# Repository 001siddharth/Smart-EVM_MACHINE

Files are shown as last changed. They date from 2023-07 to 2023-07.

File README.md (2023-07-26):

# Smart-EVM_MACHINE
**Approach Used** 
- We have stored the votes of each candidate in SR Latches and after the completion of 15 
sec from the first press of voters, the votes will be stored in the counter accumulating all the 
votes from different voters. At the end, you may press a push button to display the winner on 
7-Segment Display <br>
        **Features Added** <br>
  - Votes Comparator: The button named “Display Winner” when pressed compares the votes of all  
four candidates and prints ‘0’ if A wins, ‘1’ if B wins, ‘2’ if C wins, and ‘3’ if D wins. The 
comparator uses 3 four-bit comparator and 2 multiplexers
  - Display of Winner: The winner as output from comparator is shown on a 7-Segment Display for better 
readability on PCB. The Display will only function when the Display Winner button is 
pressed
  - MULTIPLE CANDIDATE VOTING: A voter may cast his vote(s) to any of the four candidates (one or more than one 
candidate) while only once for one candidate. The voter has a total time of 15 seconds in 
which he may cast his votes after which his votes will be registered
  - “Voted For” LEDs: Added four LEDs that display for which candidate the voter has voted. This feature 
removes any uncertainty in the minds of the voter that they might cast a wrong vote. A visual 
confirmation is the best way to remove any such confusion


  - REVERSE THE CASTED VOTE: As the votes are not registered into counters until 15 seconds have passed. The voter has this 15 seconds to alter his voting decisions. We have added four additional buttons to reverse a vote that voter may have casted mistakenly
    
  -  The ‘READY’ LED: As the votes are not registered into counters until 15 seconds have passed. The voter has this 15 seconds to alter his voting 
decisions. We have added four additional buttons to reverse a vote that voter may have cast mistakenly
  - 3 SECOND DELAY : 3-second delay is added after any button to cast a vote is pressed by the voter. 
This feature is to avoid any debouncing caused by the switch. However, as we are using SR 
Latch, which once set will not change its value until reset, overcomes this issue of 
debouncing without introducing any delay in the circuit.<br><br>
                                **PCB-layout**
<br><br>
Here as you can see in this PCB layout design we have generated the clock pulse of 
frequency 1Hz using N555 and with some resistors and capacitors. Each logic gate and 
IC’s VCC and GND terminal is connected with a connector with two inputs. Through pin
no.1 of the connector, we will supply VCC of 5V and Ground through pin no 2. Also, there 
is enable pin which will be activated by supplying 5V. And after enabling it will start 
comparing the votes of the candidates. And the result will be shown In the display attached.
We have done copper filling of Ground only because Filling a via with copper increases its 
thermal conductivity and higher conductivity will lead to high heat and may overheat the 
whole board and also may damage IC’s

<br> 
The Schematic of the Circuit <br>



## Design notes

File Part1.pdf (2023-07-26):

## DIGISIM

### PROBLEM STATEMENT 1 (PART 1)

# Team: Cool Bits

Jasnoor Sandhu (jasnoor.sandhu.ece21@itbhu.ac.in)

Siddharth Atrey (siddharth.atrey.ece21@itbhu.ac.in)

## APPROACH

We have stored the votes of each candidate in SR Latches and after the completion of 15 sec from the first press of voter, the votes will be stored in counter accumulating all the votes from different voters. At end, you may press a push button displaying the winner on 7-Segment Display.

## PCB LAYOUT

Here as you can see in this PCB layout design we have generate the clock pulse of frequency 1Hz using N555 and with some resistors and capacitors. Each logic gates and IC’s VCC and GND terminal is connected with connector with two inputs. Through pin no.1 of the connector we will supply VCC of 5V and Ground through pin no 2 . Also there is enable pin which will be activated by supplying 5V. And after enabling it will start comparing the votes of the candidates. And result will be shown In the display attached.

We have done copper filling of Ground only because Filling a via with copper increases its thermal conductivity and higher conductivity will lead to high heat and may overheat the whole board and also may damage IC’s.

DIGISIM - COOL BITS | 1

## FEATURES

1. VOTES COMPARATOR :
The button named “Display Winner” when pressed compares the votes of all the four candidates and prints ‘0’ if A wins, ‘1’ if B wins, ‘2’ if C wins and ‘3’ if D wins. The comparator uses 3 four-bit comparator and 2 multiplexers.
2. DISPLAY OF WINNER :
The winner as output from comparator is shown on a 7-Segment Display for better readability on PCB. The Display will only function when the Display winner button is pressed.

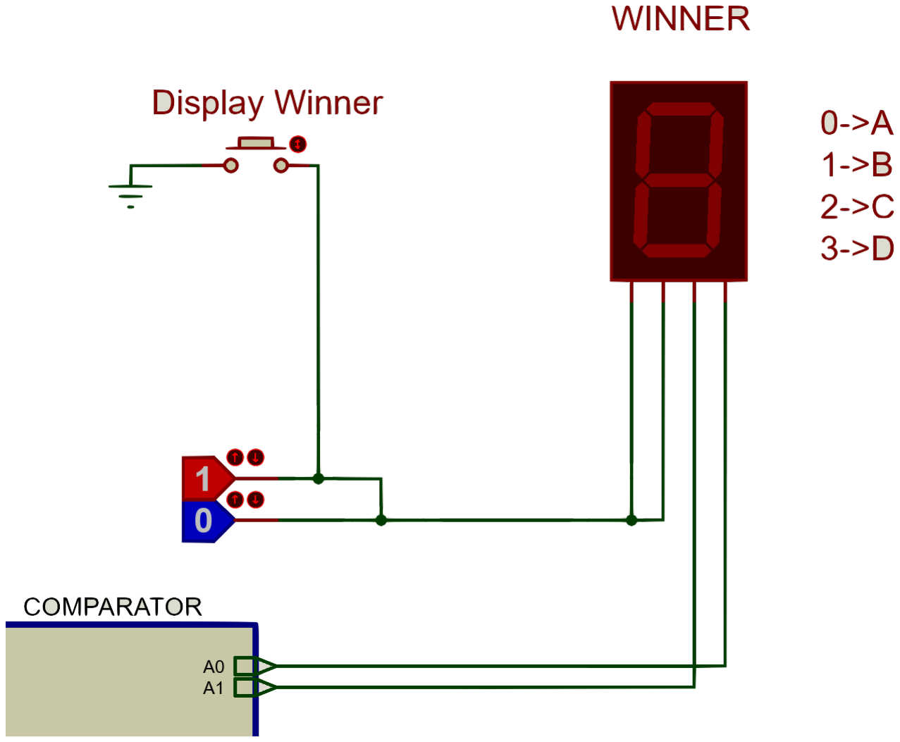
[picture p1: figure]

3. MULTIPLE CANDIDATE VOTING :
A voter may cast his vote(s) to any of the four candidates (one or more than one candidate) while only once for one candidate. The voter has a total time of 15 seconds in which he may cast his votes after which his votes will be registered.
4. “Voted For” LEDs :
Added four LEDs that display for which candidate the voter has voted. This feature removes any uncertainty in minds of the voter that they might cast a wrong vote. A visual confirmation is best way to remove any such confusion

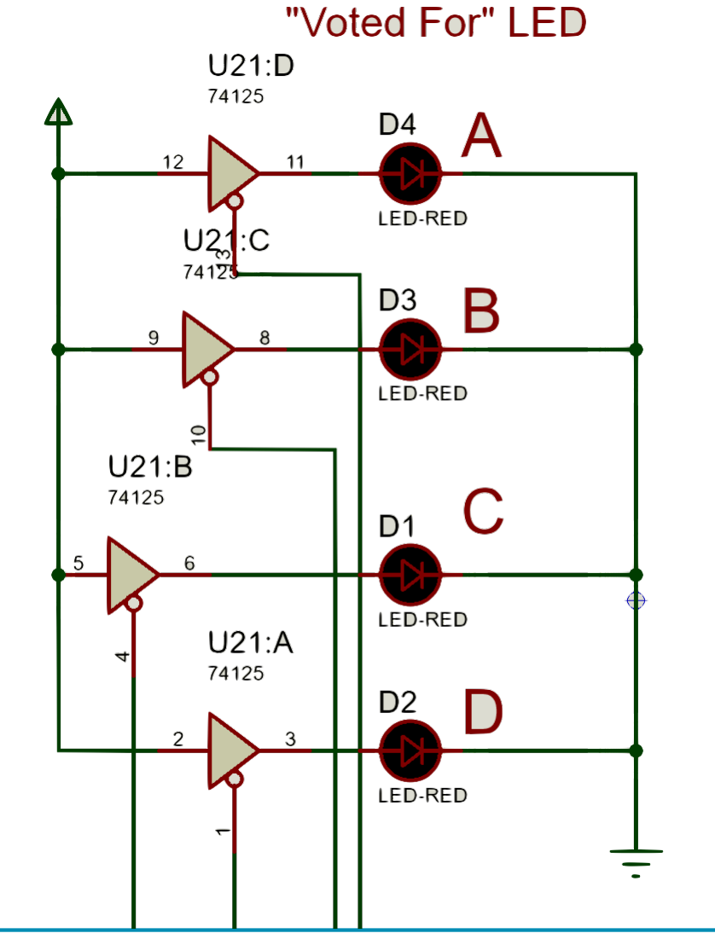
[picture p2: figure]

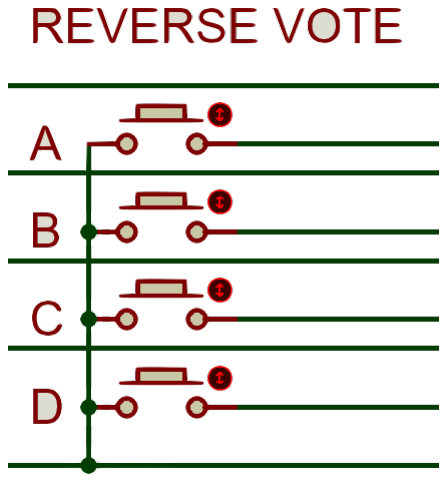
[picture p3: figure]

5. REVERSE THE CASTED VOTE :
As the votes are not registered into counters until 15 seconds have passed. The voter has this 15 seconds to alter his voting decisions. We have added four additional buttons to reverse a vote that voter may have casted mistakenly.
6. THE ‘READY’ LED :

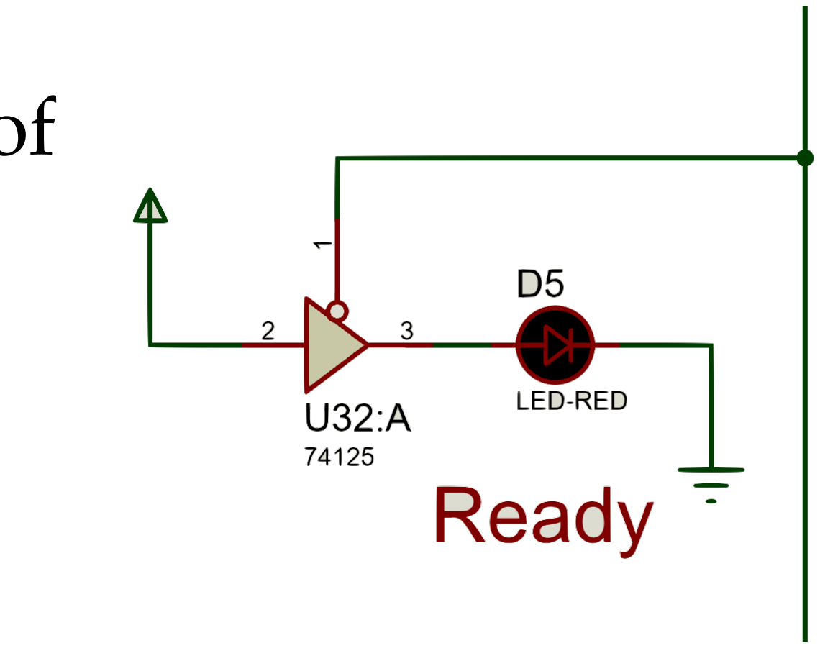
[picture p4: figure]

As the machine doesn’t take input from voter within 3 sec of a button press. A ‘Ready’ LED is present which indicates that the machine is ready for another input. So the user my input another
vote if he wants to.
7. 3 SECOND DELAY :
A 3 second delay is added after any button to cast vote is pressed by the voter. This feature is to avoid any debouncing caused by switch. However, as we are using SR Latch, which once set will not change its value until reset, overcomes this issue of debouncing without introducing any delay in circuit.

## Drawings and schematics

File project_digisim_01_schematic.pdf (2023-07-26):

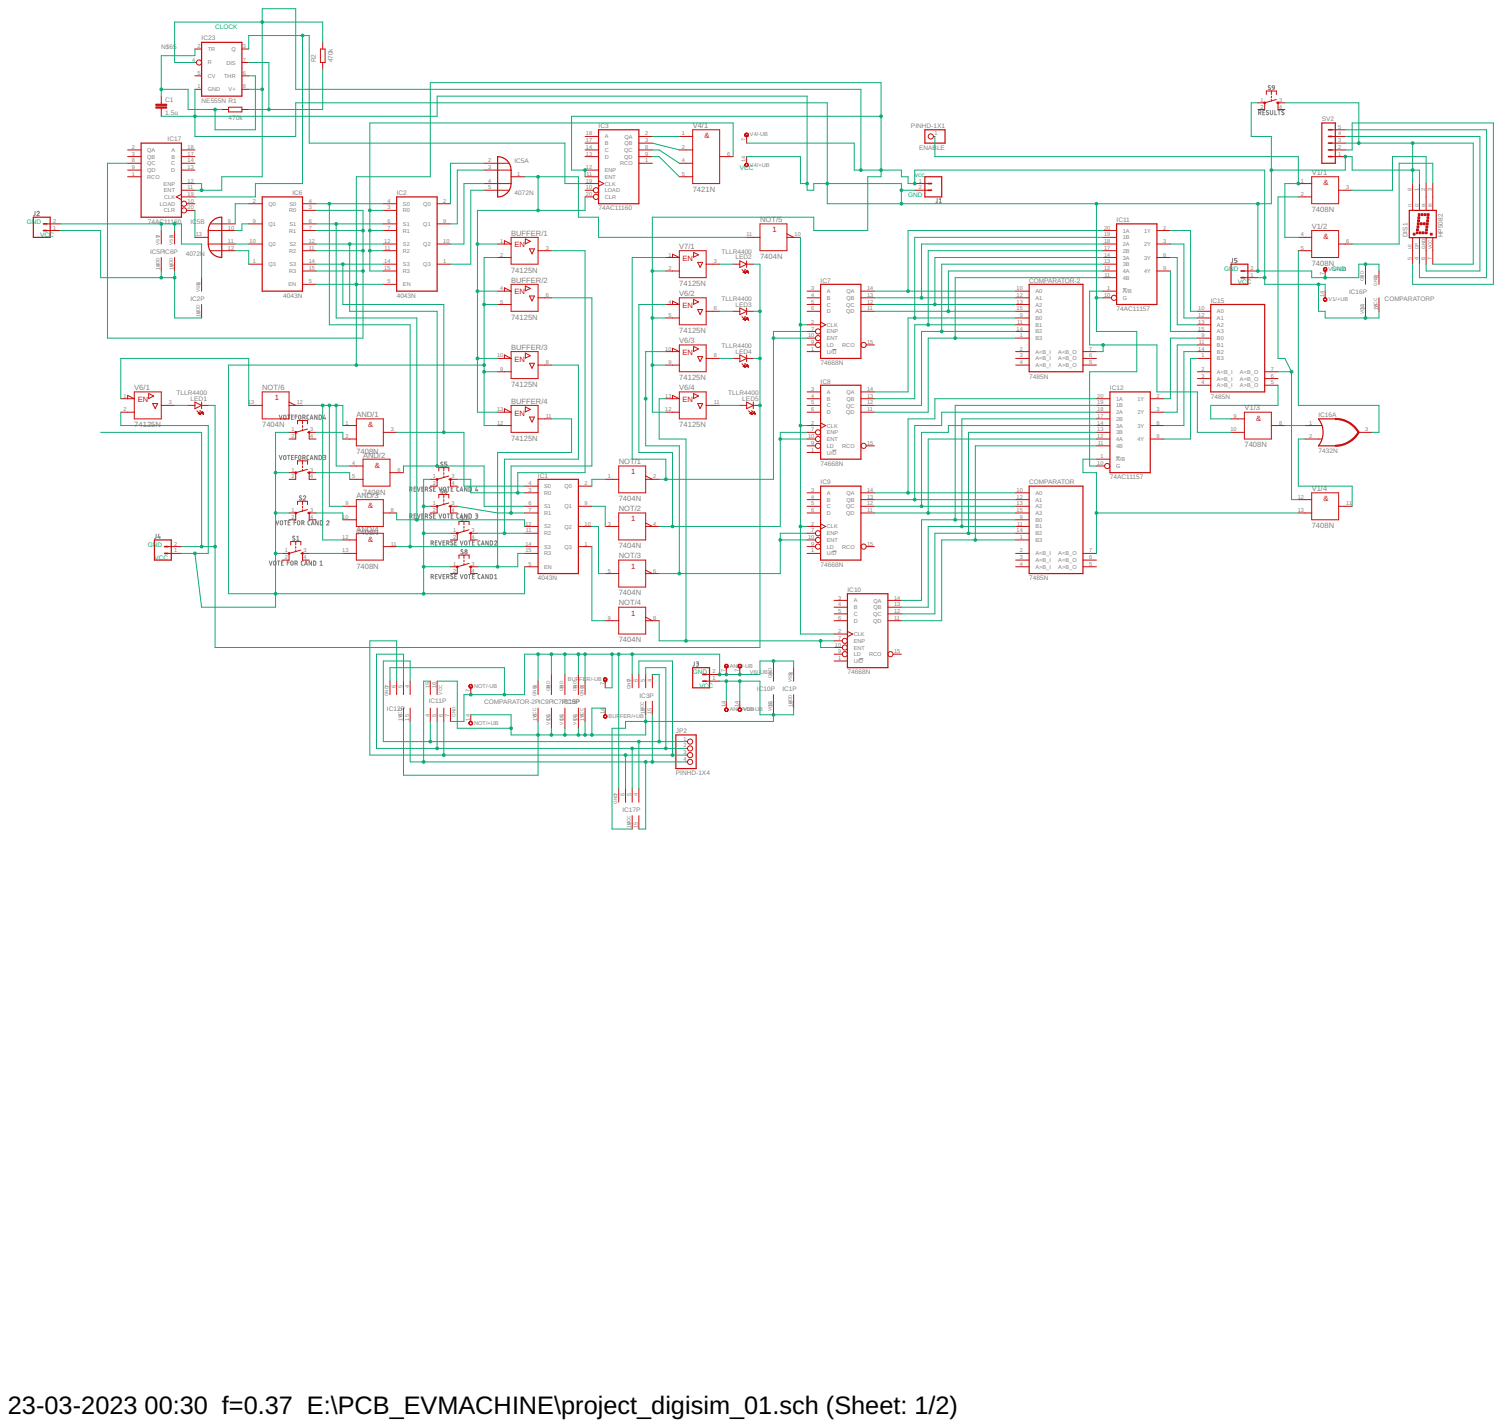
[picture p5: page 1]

3 4

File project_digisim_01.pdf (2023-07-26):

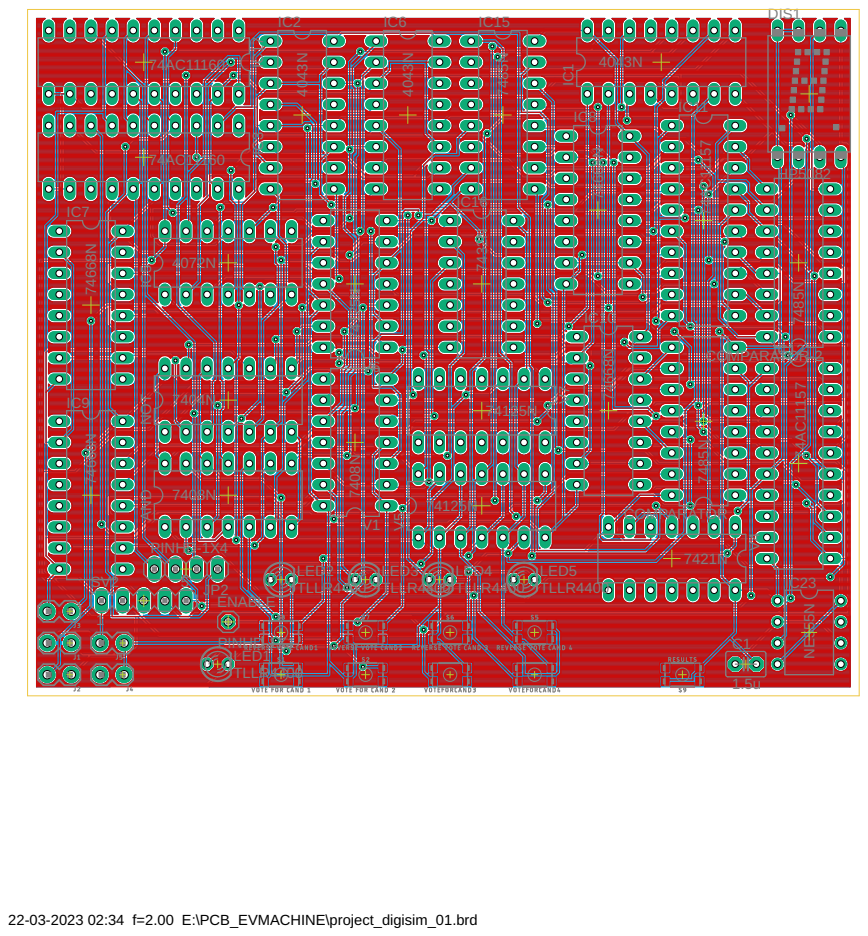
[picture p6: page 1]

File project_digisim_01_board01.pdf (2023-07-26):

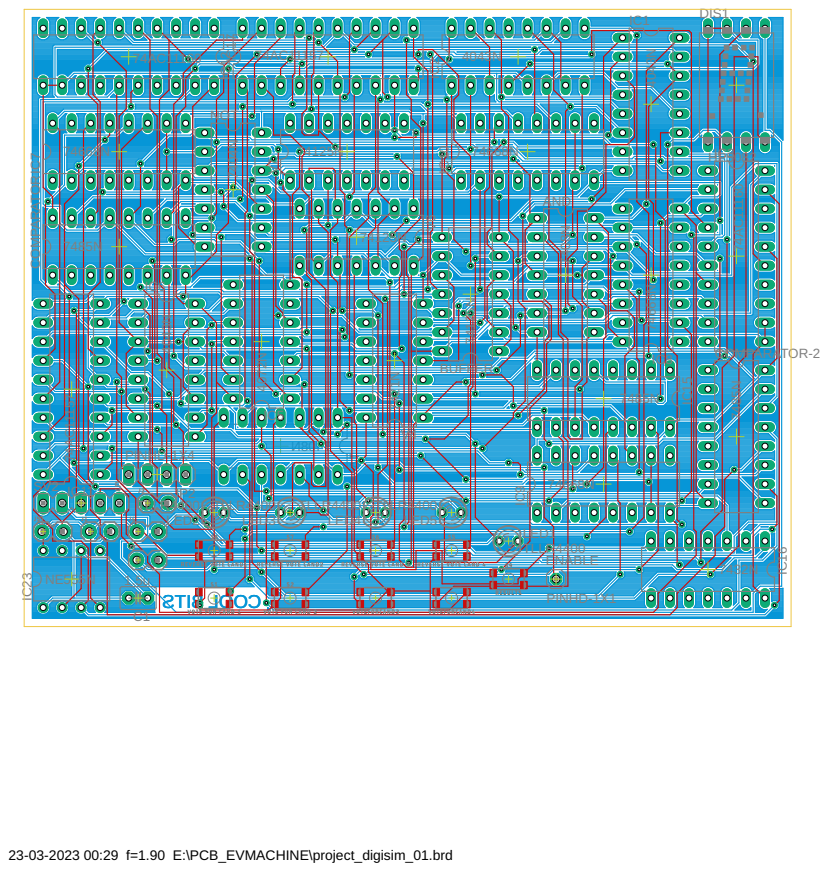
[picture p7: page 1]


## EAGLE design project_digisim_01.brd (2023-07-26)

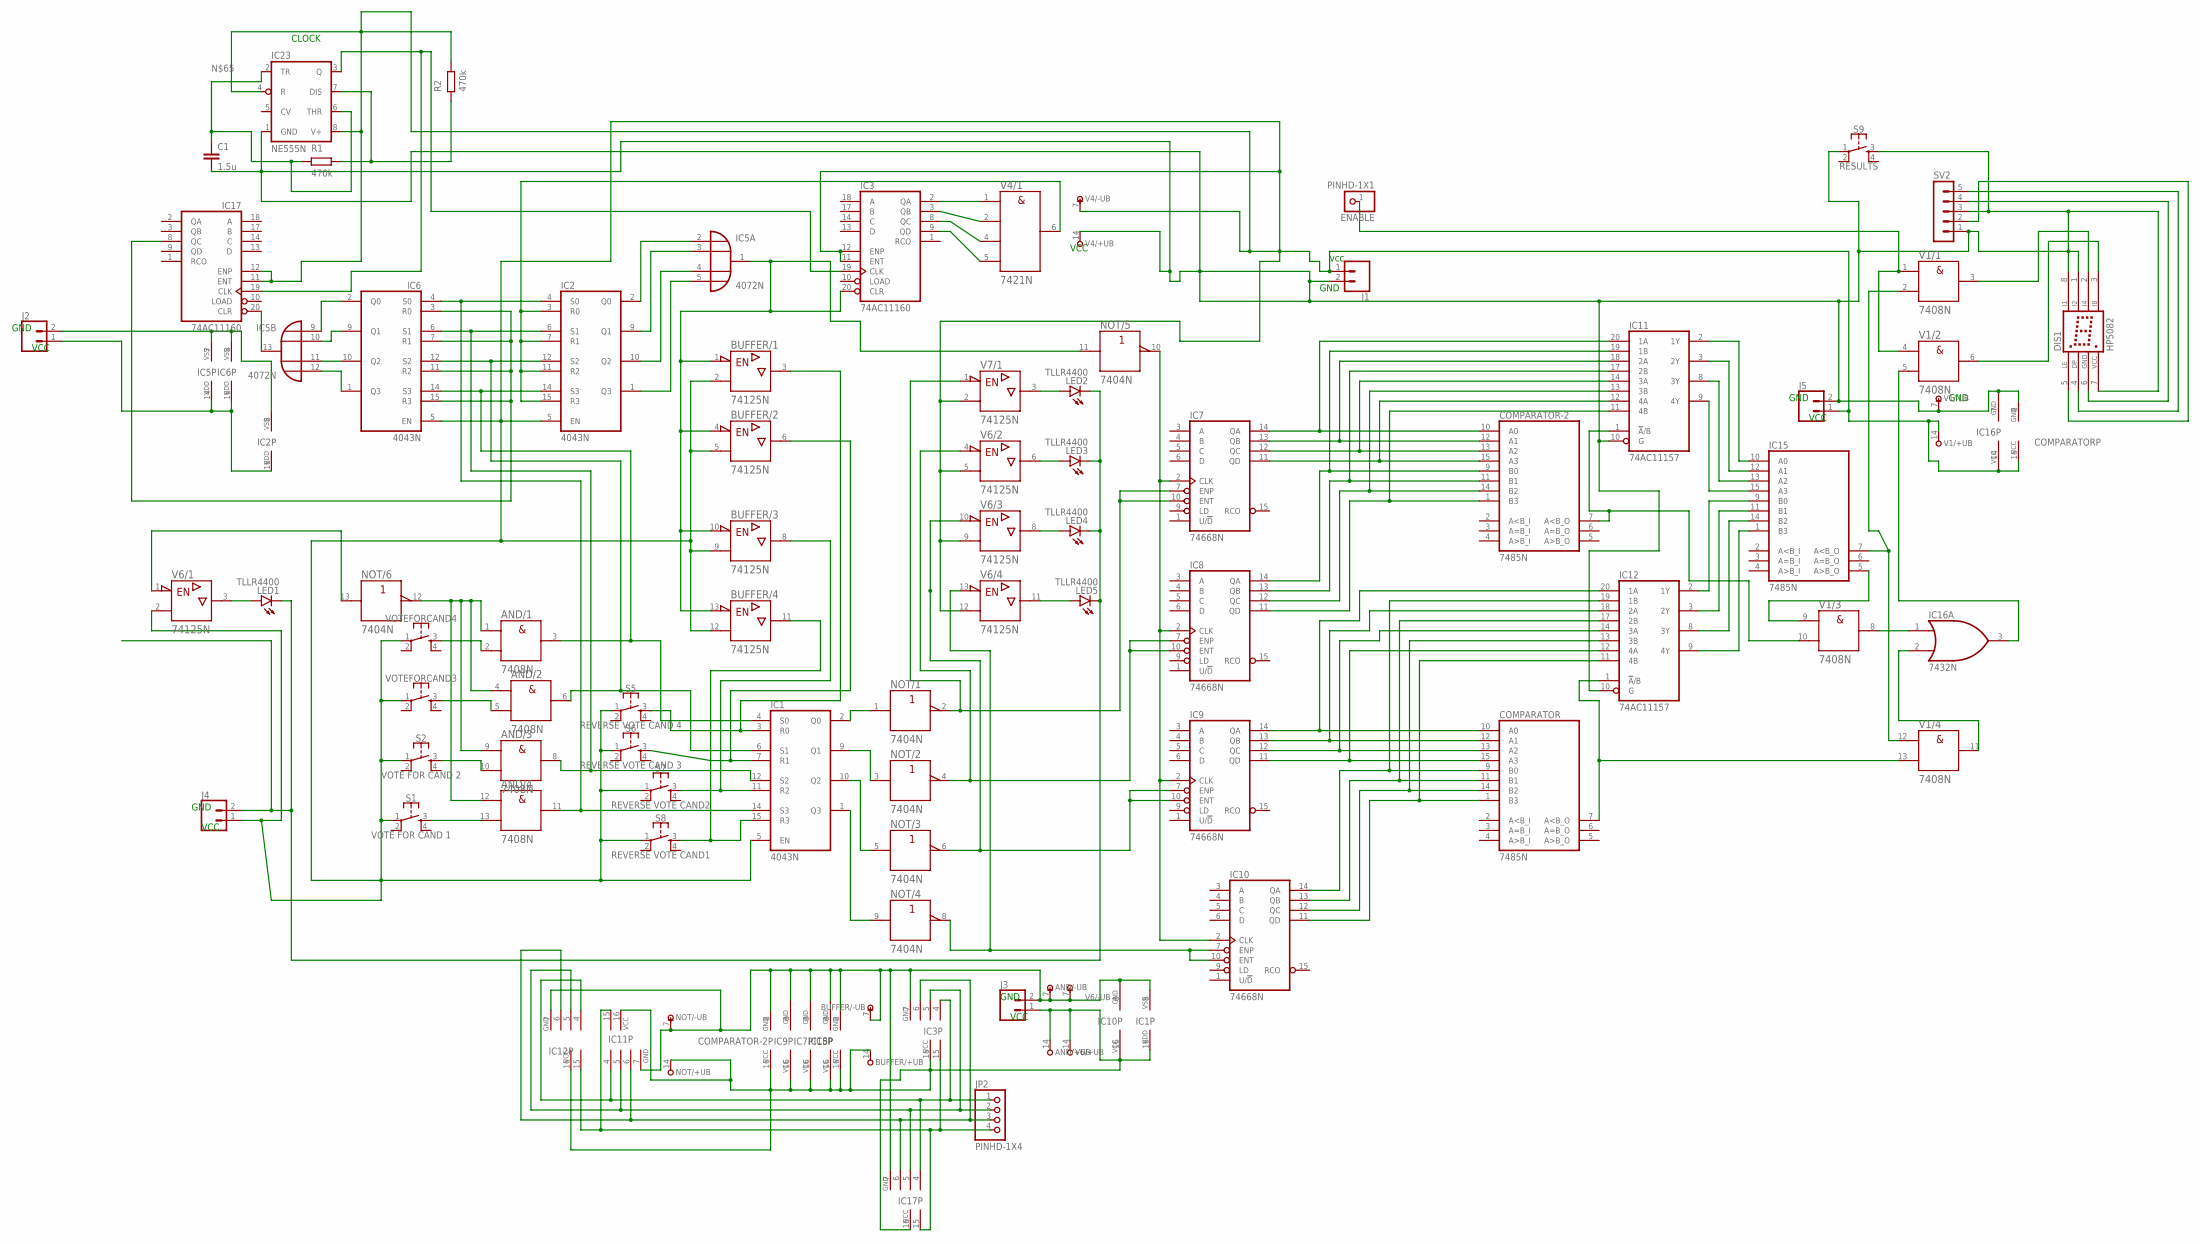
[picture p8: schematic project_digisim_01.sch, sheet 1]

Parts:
AND: 7408N; DIL14
BUFFER: 74125N; DIL14
C1: 1.5u; C2.5-3
COMPARATOR: 7485N; DIL16
COMPARATOR-2: 7485N; DIL16
DIS1: HP5082
ENABLE: PINHD-1X1; 1X01
IC1, IC2, IC6: 4043N; DIL16
IC3, IC17: 74AC11160; DIL20
IC5: 4072N; DIL14
IC7, IC8, IC9, IC10: 74668N; DIL16
IC11, IC12: 74AC11157; DIL20
IC15: 7485N; DIL16
IC16: 7432N; DIL14
IC23: NE555N; DIL08
J1, J2, J3, J4, J5: CONN_02LOCK; 1X02_LOCK
JP2: PINHD-1X4; 1X04
LED1, LED2, LED3, LED4, LED5: TLLR4400; LED3MM
NOT: 7404N; DIL14
S1: VOTE FOR CAND 1; TACTILE_SWITCH_SMD_4.6X2.8MM
S2: VOTE FOR CAND 2; TACTILE_SWITCH_SMD_4.6X2.8MM
S5: REVERSE VOTE CAND 4; TACTILE_SWITCH_SMD_4.6X2.8MM
S6: REVERSE VOTE CAND 3; TACTILE_SWITCH_SMD_4.6X2.8MM
S7: REVERSE VOTE CAND2; TACTILE_SWITCH_SMD_4.6X2.8MM
S8: REVERSE VOTE CAND1; TACTILE_SWITCH_SMD_4.6X2.8MM
S9: RESULTS; TACTILE_SWITCH_SMD_4.6X2.8MM
SV2: MA05-1
V1: 7408N; DIL14
V4: 7421N; DIL14
V6, V7: 74125N; DIL14
VOTEFORCAND3, VOTEFORCAND4: MOMENTARY-SWITCH-SPST-2-SMD-4.6X2.8MM; TACTILE_SWITCH_SMD_4.6X2.8MM

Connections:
+UB: V7.14 (+UB)
-UB: V7.7 (-UB)
unnamed: AND.3 (Y), IC1.4 (S0), IC2.14 (S3), IC6.14 (S3)
unnamed: IC10.7 (ENP), IC10.10 (ENT), NOT.8 (Y), V6.13 (!G)
unnamed: IC2.2 (Q0), IC5.2 (I0)
unnamed: AND.8 (Y), IC1.12 (S2), IC2.6 (S1), IC6.6 (S1)
unnamed: DIS1.3 (I8), V1.6 (Y)
unnamed: BUFFER.3 (Y), IC1.3 (R0), S5.3
unnamed: BUFFER.6 (Y), IC1.7 (R1), S6.3
unnamed: BUFFER.11 (Y), IC1.15 (R3), S8.3
unnamed: IC1.2 (Q0), NOT.1 (A)
unnamed: IC1.9 (Q1), NOT.3 (A)
unnamed: NOT.13 (A), V6.1 (!G)
unnamed: IC1.10 (Q2), NOT.5 (A)
unnamed: LED2.A, V7.3 (Y)
unnamed: IC1.1 (Q3), NOT.9 (A)
unnamed: LED3.A, V6.6 (Y)
unnamed: IC7.7 (ENP), IC7.10 (ENT), NOT.2 (Y), V7.1 (!G)
unnamed: IC16.1 (I0), V1.8 (Y)
unnamed: IC2.8 (VSS), IC5.7 (VSS), IC6.8 (VSS), J2.2
unnamed: COMPARATOR-2.10 (A0), IC7.14 (QA), IC11.20 (1A)
unnamed: COMPARATOR-2.12 (A1), IC7.13 (QB), IC11.18 (2A)
unnamed: LED4.A, V6.8 (Y)
unnamed: COMPARATOR-2.13 (A2), IC7.12 (QC), IC11.14 (3A)
unnamed: COMPARATOR-2.15 (A3), IC7.11 (QD), IC11.12 (4A)
unnamed: COMPARATOR-2.9 (B0), IC8.14 (QA), IC11.19 (1B)
unnamed: COMPARATOR-2.11 (B1), IC8.13 (QB), IC11.17 (2B)
unnamed: COMPARATOR-2.14 (B2), IC8.12 (QC), IC11.13 (3B)
unnamed: COMPARATOR-2.1 (B3), IC8.11 (QD), IC11.11 (4B)
unnamed: COMPARATOR.10 (A0), IC9.14 (QA), IC12.20 (1A)
unnamed: COMPARATOR.12 (A1), IC9.13 (QB), IC12.18 (2A)
unnamed: COMPARATOR.13 (A2), IC9.12 (QC), IC12.14 (3A)
unnamed: COMPARATOR.15 (A3), IC9.11 (QD), IC12.12 (4A)
unnamed: COMPARATOR.9 (B0), IC10.14 (QA), IC12.19 (1B)
unnamed: COMPARATOR.11 (B1), IC10.13 (QB), IC12.17 (2B)
unnamed: COMPARATOR.14 (B2), IC10.12 (QC), IC12.13 (3B)
unnamed: COMPARATOR.1 (B3), IC10.11 (QD), IC12.11 (4B)
unnamed: IC11.2 (1Y), IC15.10 (A0)
unnamed: IC11.3 (2Y), IC15.12 (A1)
unnamed: IC11.8 (3Y), IC15.13 (A2)
unnamed: IC11.9 (4Y), IC15.15 (A3)
unnamed: IC12.2 (1Y), IC15.9 (B0)
unnamed: IC12.3 (2Y), IC15.11 (B1)
unnamed: IC12.8 (3Y), IC15.14 (B2)
unnamed: IC12.9 (4Y), IC15.1 (B3)
unnamed: COMPARATOR-2.7 (A<B_O), IC11.1 (!A!/B), V1.10 (B)
unnamed: COMPARATOR.7 (A<B_O), IC12.1 (!A!/B), V1.13 (B)
unnamed: AND.11 (Y), IC1.14 (S3), IC2.4 (S0), IC6.4 (S0)
unnamed: IC15.5 (A>B_O), V1.9 (A)
unnamed: ENABLE.1, V1.1 (A), V1.4 (A)
unnamed: IC2.16 (VDD), IC5.14 (VDD), IC6.16 (VDD), J2.1
unnamed: IC16.2 (I1), V1.11 (Y)
unnamed: IC3.19 (CLK), IC17.19 (CLK), IC23.3 (Q)
unnamed: IC2.9 (Q1), IC5.3 (I1)
unnamed: IC2.10 (Q2), IC5.4 (I2)
unnamed: IC2.1 (Q3), IC5.5 (I3)
unnamed: BUFFER.8 (Y), IC1.11 (R2), S7.3
unnamed: LED5.A, V6.11 (Y)
unnamed: IC16.3 (O), V1.5 (B)
unnamed: IC8.7 (ENP), IC8.10 (ENT), NOT.4 (Y), V6.4 (!G)
unnamed: DIS1.2 (I4), V1.3 (Y)
unnamed: IC7.2 (CLK), IC8.2 (CLK), IC9.2 (CLK), IC10.2 (CLK), NOT.10 (Y)
unnamed: J4.2, LED1.K (C), LED2.K (C), LED3.K (C), LED4.K (C), LED5.K (C)
unnamed: IC15.7 (A<B_O), V1.2 (B), V1.12 (A)
unnamed: AND.6 (Y), IC1.6 (S1), IC2.12 (S2), IC6.12 (S2)
unnamed: LED1.A, V6.3 (Y)
unnamed: C1.1, IC23.2 (TR), IC23.6 (THR)
unnamed: AND.2 (B), VOTEFORCAND4.3
unnamed: AND.5 (B), VOTEFORCAND3.3
unnamed: AND.10 (B), S2.3
unnamed: AND.13 (B), S1.3
unnamed: AND.1 (A), AND.4 (A), AND.9 (A), AND.12 (A), NOT.12 (Y)
unnamed: IC3.2 (QA), V4.1 (A)
unnamed: IC3.3 (QB), V4.2 (B)
unnamed: IC3.8 (QC), V4.4 (C)
unnamed: IC3.9 (QD), V4.5 (D)
unnamed: IC2.3 (R0), IC2.7 (R1), IC2.11 (R2), IC2.15 (R3), V4.6 (Y)
unnamed: IC5.13 (O), IC17.20 (CLR)
unnamed: IC5.9 (I0), IC6.2 (Q0)
unnamed: IC5.10 (I1), IC6.9 (Q1)
unnamed: IC5.11 (I2), IC6.10 (Q2)
unnamed: IC5.12 (I3), IC6.1 (Q3)
unnamed: IC6.3 (R0), IC6.7 (R1), IC6.11 (R2), IC6.15 (R3), IC17.8 (QC)
unnamed: BUFFER.2 (A), BUFFER.5 (A), BUFFER.9 (A), BUFFER.12 (A), COMPARATOR.16 (VCC), IC1.5 (EN), IC2.5 (EN), IC3.11 (ENT), IC3.12 (ENP), IC6.5 (EN), IC16.14 (VCC), IC17.11 (ENT), IC17.12 (ENP), IC23.4 (R), IC23.8 (V+), J1.1, J4.1, J5.1, S1.1, S2.1, S5.1, S6.1, S7.1, S8.1, V1.14 (+UB), V4.7 (-UB), V6.2 (A), V6.5 (A), V6.9 (A), V6.12 (A), V7.2 (A), VOTEFORCAND3.1, VOTEFORCAND4.1
unnamed: IC9.7 (ENP), IC9.10 (ENT), NOT.6 (Y), V6.10 (!G)
unnamed: C1.2, COMPARATOR.8 (GND), DIS1.1 (I2), DIS1.7 (VCC), DIS1.8 (I1), IC11.10 (G), IC12.10 (G), IC16.7 (GND), IC23.1 (GND), J1.2, J5.2, S9.1, S9.3, SV2.1, SV2.3, V1.7 (-UB), V4.14 (+UB)
unnamed: DIS1.6 (GND), SV2.4
unnamed: DIS1.4 (DP), SV2.5
unnamed: BUFFER.1 (!G), BUFFER.4 (!G), BUFFER.10 (!G), BUFFER.13 (!G), IC3.20 (CLR), IC5.1 (O), NOT.11 (A)
unnamed: DIS1.5 (LE), SV2.2
unnamed: AND.7 (-UB), BUFFER.7 (-UB), COMPARATOR-2.8 (GND), IC1.8 (VSS), IC3.7 (GND), IC7.8 (GND), IC8.8 (GND), IC9.8 (GND), IC10.8 (GND), IC11.7 (GND), IC12.7 (GND), IC15.8 (GND), IC17.7 (GND), J3.2, NOT.7 (-UB), V6.7 (-UB)
unnamed: AND.14 (+UB), BUFFER.14 (+UB), COMPARATOR-2.16 (VCC), IC1.16 (VDD), IC3.16 (VCC), IC7.16 (VCC), IC8.16 (VCC), IC9.16 (VCC), IC10.16 (VCC), IC11.16 (VCC), IC12.16 (VCC), IC15.16 (VCC), IC17.16 (VCC), J3.1, NOT.14 (+UB), V6.14 (+UB)
unnamed: IC3.4 (GND), IC11.4 (GND), IC12.4 (GND), IC17.4 (GND), JP2.1
unnamed: IC3.5 (GND), IC11.5 (GND), IC12.5 (GND), IC17.5 (GND), JP2.2
unnamed: IC3.15 (VCC), IC11.15 (VCC), IC12.15 (VCC), IC17.15 (VCC), JP2.4
unnamed: IC3.6 (GND), IC11.6 (GND), IC12.6 (GND), IC17.6 (GND), JP2.3

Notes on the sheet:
CLOCK
vcc
GND
VCC

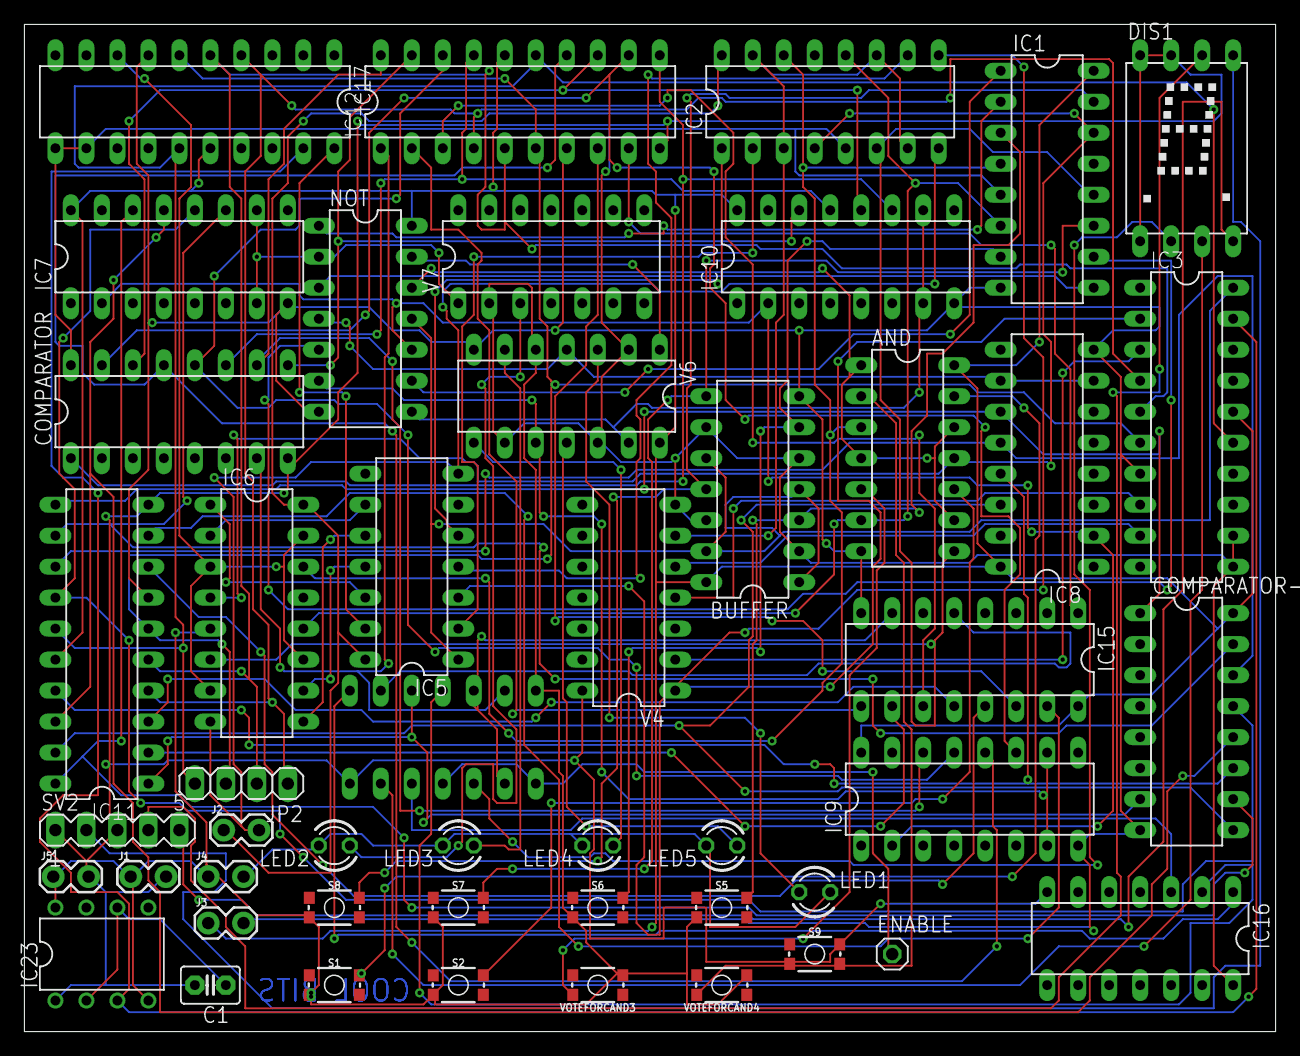
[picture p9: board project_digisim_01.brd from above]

Board: 2 copper layers, 102.5 x 82.5 mm, 48 parts (1 on the bottom side), 94 nets.

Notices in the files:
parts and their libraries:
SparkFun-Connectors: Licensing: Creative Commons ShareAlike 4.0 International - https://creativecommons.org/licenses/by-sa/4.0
